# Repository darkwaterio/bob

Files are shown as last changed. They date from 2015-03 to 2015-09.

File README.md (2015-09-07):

#Bob Mk1 - "Ides"

This repository contains the hardware and firmware files for Mk1 of the Bob Float (codenamed "Ides").

This version was built for demonstration at the Big Bang Fair 2015 and is the first deployment of Bob. There are quite a few niggles to be fixed and updates that are planned for Bob based on the findings from this version, so it's not recommended that you spend much time with it - however, there will be a lot of cross-over of parts with the next version so you wouldn't need to rebuild everything for Mk2

Mk2 can be found at https://github.com/darkwaterfoundation/bob/tree/mk2

##Repository Layout

- hardware - contains three directories
  - stl contains the 3D printed parts files
  - svg contains the laser cutting files - you may need to alter the outside widths of circles based on the kerf of your cutter
  - pcb contains the eagle files for the power board and the processing board. The processing board is designed for use with the Spark Core. Some tweaks may be needed for the Spark Photon but you *should* be able to use the same board.
- firmware - contains the firmware for the demonstration version of Bob, this accepts commands over the Spark / Bob cloud and performs functions based on that (flashing lights / diving for x seconds) - it doesn't contain depth based functionality (other than reporting) as the tank we used was only a meter deep :)

##Preliminary Bill of Materials

https://docs.google.com/spreadsheets/d/1KixPCNF-eNdthVP5A6QqYoAs1JIhs3zF5F2K2lznduw/edit?usp=sharing

##Build instructions

Will be up soon

##License

This work is licensed under the Creative Commons Attribution-NonCommercial-ShareAlike 4.0 International License. To view a copy of this license, visit http://creativecommons.org/licenses/by-nc-sa/4.0/ or send a letter to Creative Commons, 444 Castro Street, Suite 900, Mountain View, California, 94041, USA.

*Some portions of code may be subject to different licensing agreements.

THE SOFTWARE IS PROVIDED “AS IS”, WITHOUT WARRANTY OF ANY KIND, EXPRESS OR IMPLIED, INCLUDING BUT NOT LIMITED TO THE WARRANTIES OF MERCHANTABILITY, FITNESS FOR A PARTICULAR PURPOSE AND NONINFRINGEMENT. IN NO EVENT SHALL THE AUTHORS OR COPYRIGHT HOLDERS BE LIABLE FOR ANY CLAIM, DAMAGES OR OTHER LIABILITY, WHETHER IN AN ACTION OF CONTRACT, TORT OR OTHERWISE, ARISING FROM, OUT OF OR IN CONNECTION WITH THE SOFTWARE OR THE USE OR OTHER DEALINGS IN THE SOFTWARE.

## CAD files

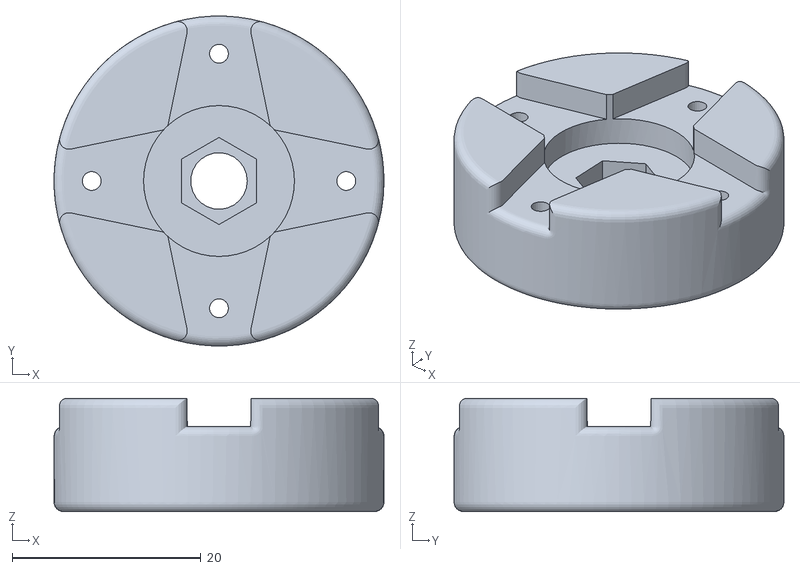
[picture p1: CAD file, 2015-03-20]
hardware/stl/servohorn.stl
35.0 x 35.0 x 12.0

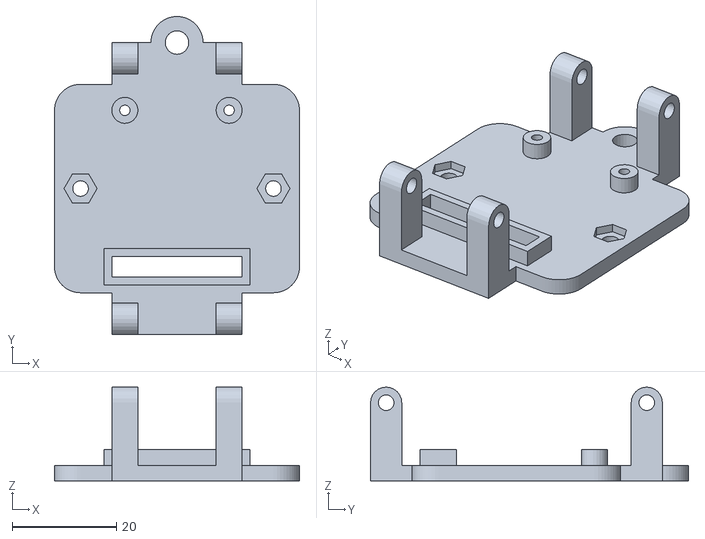
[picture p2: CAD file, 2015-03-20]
hardware/stl/gpsholder.stl
47.0 x 61.0 x 18.0

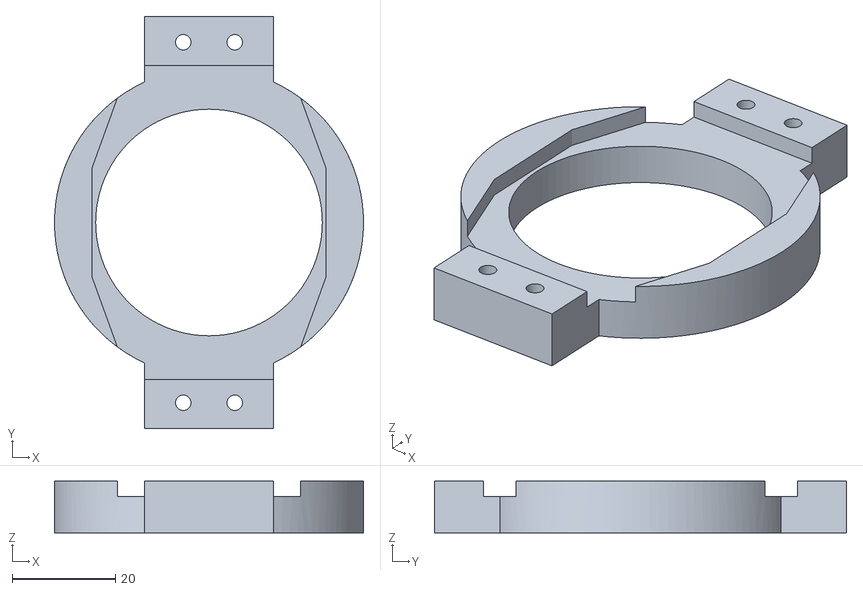
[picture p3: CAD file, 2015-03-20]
hardware/stl/syringeholder.stl
60.0 x 80.0 x 10.0

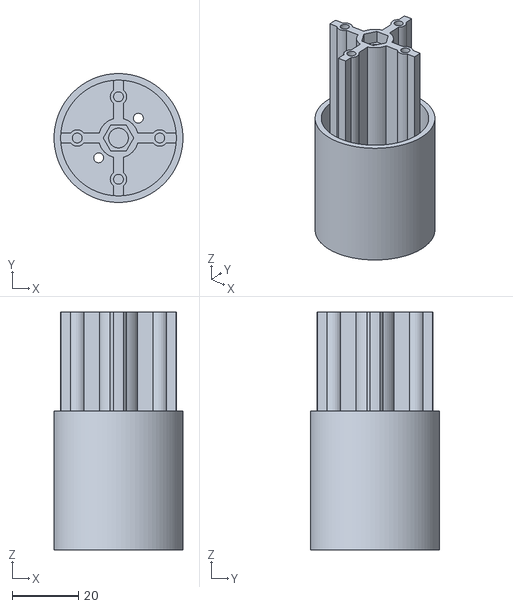
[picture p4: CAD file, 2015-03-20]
hardware/stl/plungerbody.stl
39.0 x 39.0 x 72.0

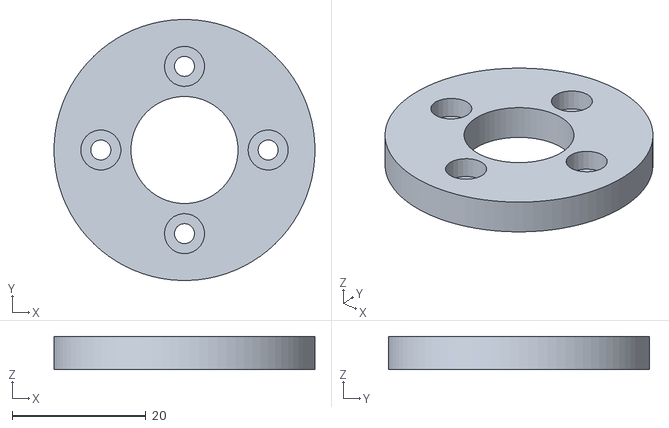
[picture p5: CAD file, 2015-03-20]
hardware/stl/bearingholder.stl
39.0 x 39.0 x 5.00

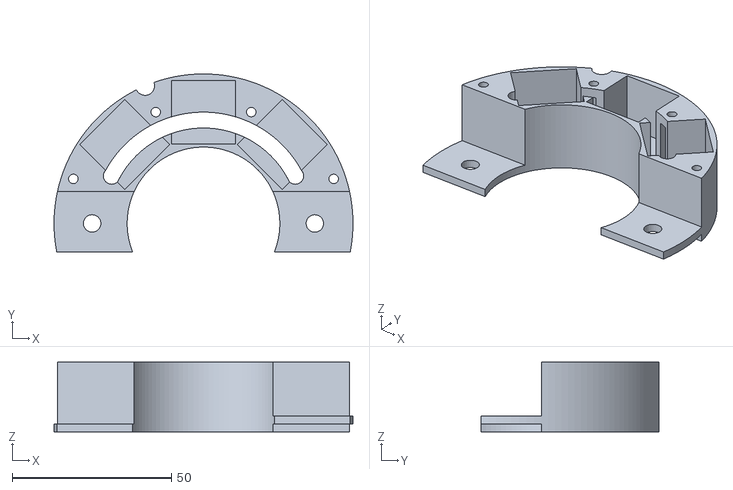
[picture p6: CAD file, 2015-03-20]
hardware/stl/batterydeepend.stl
94.0 x 56.0 x 22.0

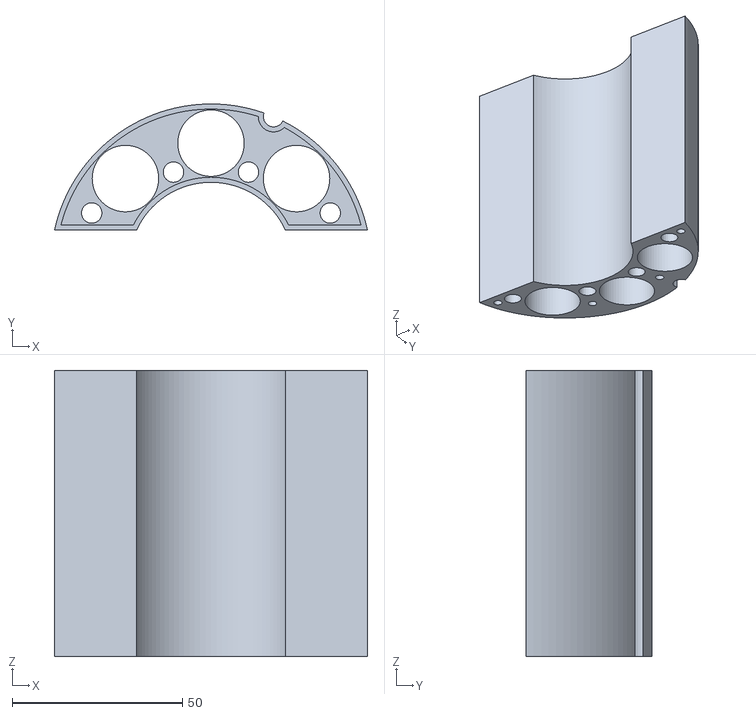
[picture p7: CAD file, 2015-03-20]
hardware/stl/outerbatteryholder.stl
91.8 x 37.0 x 84.0

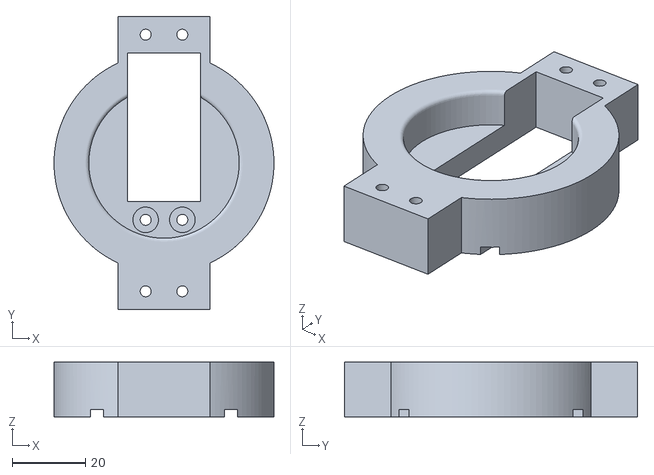
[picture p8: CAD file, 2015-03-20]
hardware/stl/servoholder.stl
60.0 x 80.0 x 15.0

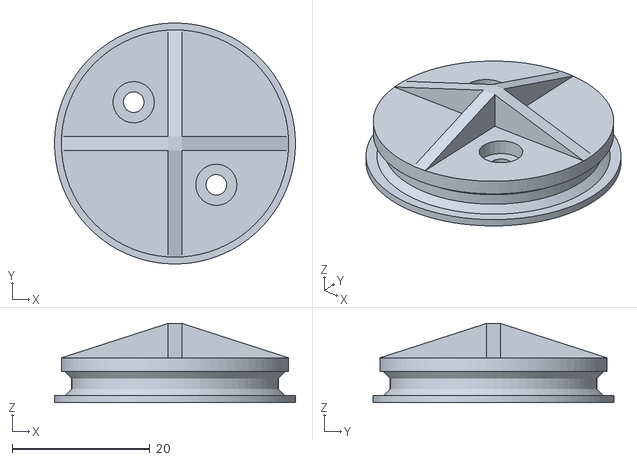
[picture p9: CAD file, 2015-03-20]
hardware/stl/plungerend.stl
35.0 x 35.0 x 11.5

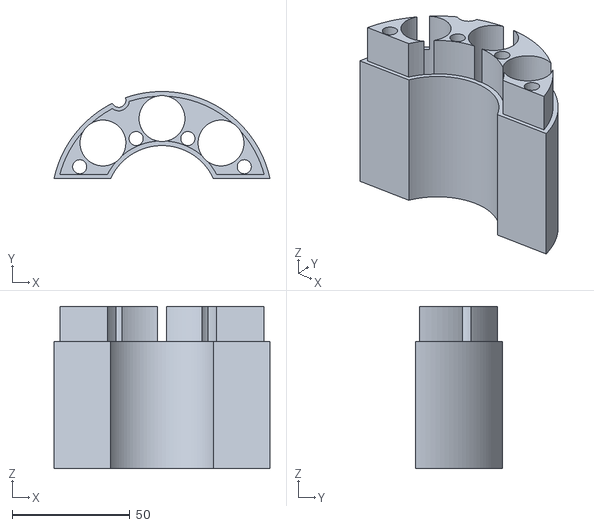
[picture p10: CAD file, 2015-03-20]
hardware/stl/innerbatteryholder.stl
91.8 x 37.0 x 69.0

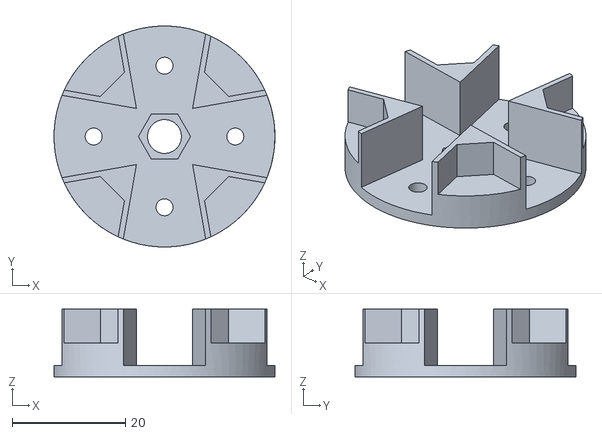
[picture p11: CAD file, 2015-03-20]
hardware/stl/magnetholder.stl
39.0 x 39.0 x 12.0

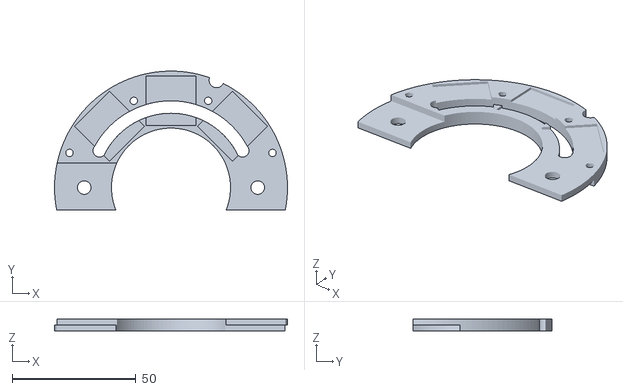
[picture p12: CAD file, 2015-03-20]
hardware/stl/batteryshallowend.stl
94.0 x 56.0 x 5.00

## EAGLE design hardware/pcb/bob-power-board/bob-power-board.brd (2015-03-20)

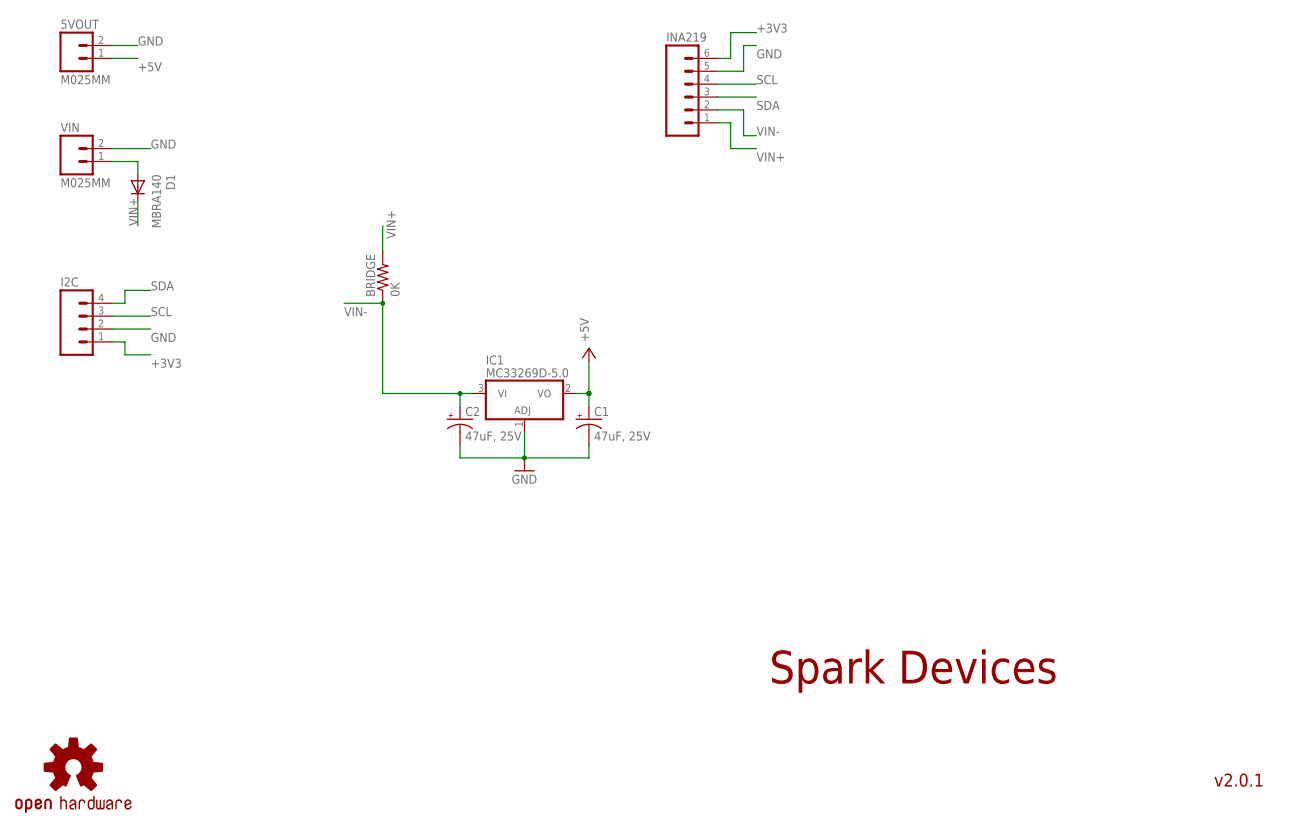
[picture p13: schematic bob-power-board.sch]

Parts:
5VOUT: M025MM; SCREWTERMINAL-5MM-2
BRIDGE: 0K; 1206
C1, C2: 47uF, 25V; CPOL-RADIAL-100UF-25V
D1: MBRA140; SMA-DIODE
I2C: M04LOCK; 1X04_LOCK
IC1: MC33269D-5.0; DPACK
INA219: M06LOCK; 1X06_LOCK
LOGO1: OSHW-LOGOM; OSHW-LOGO-M
VIN: M025MM; SCREWTERMINAL-5MM-2

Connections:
+3V3: I2C.1, INA219.6
+5V: 5VOUT.1, C1.1 (+), IC1.2 (VO)
GND: 5VOUT.2, C1.2 (-), C2.2 (-), I2C.2, IC1.1 (ADJ), INA219.5, VIN.2
unnamed: D1.A, VIN.1
SCL: I2C.3, INA219.4
SDA: I2C.4, INA219.3
VIN+: BRIDGE.2, D1.C, INA219.1
VIN-: BRIDGE.1, C2.1 (+), IC1.3 (VI), INA219.2

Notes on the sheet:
Spark Devices
v2.0.1

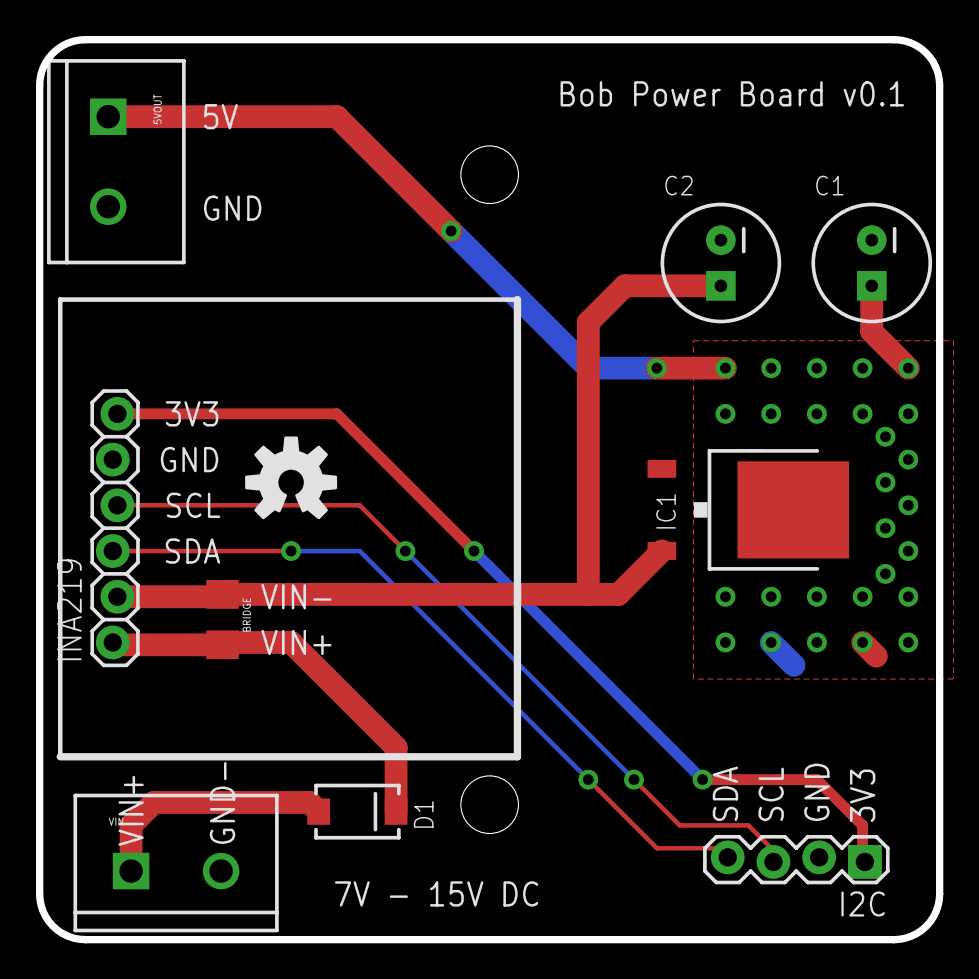
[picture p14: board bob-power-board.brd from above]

Board: 2 copper layers, 50.0 x 50.0 mm, 10 parts (0 on the bottom side), 8 nets.

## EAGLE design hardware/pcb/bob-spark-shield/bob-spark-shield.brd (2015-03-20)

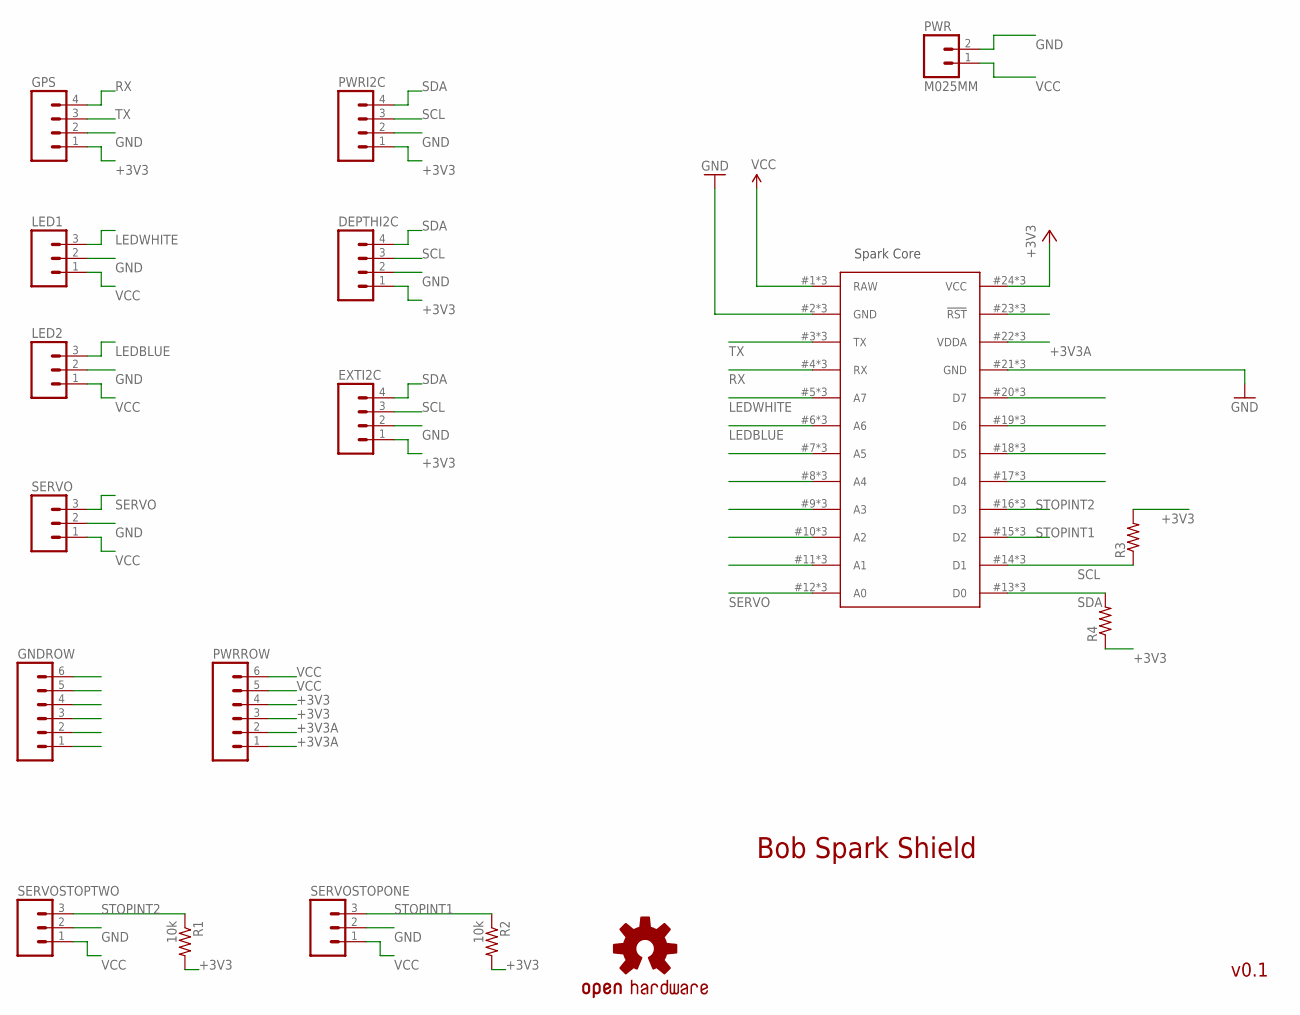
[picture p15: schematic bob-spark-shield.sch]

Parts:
DEPTHI2C: M04LOCK; 1X04_LOCK
EXTI2C: M04LOCK; 1X04_LOCK
GNDROW: M06LOCK; 1X06_LOCK
GPS: M04LOCK; 1X04_LOCK
LED1, LED2: M03LOCK; 1X03_LOCK
LOGO1: OSHW-LOGOM; OSHW-LOGO-M
PWR: M025MM; SCREWTERMINAL-5MM-2
PWRI2C: M04LOCK; 1X04_LOCK
PWRROW: M06LOCK; 1X06_LOCK
R1, R2: 10k; 0805
R3, R4: RESISTOR0805-RES; 0805
SERVO: M03LOCK; 1X03_LOCK
SERVOSTOPONE: M03LOCK; 1X03_LOCK
SERVOSTOPTWO: M03LOCK; 1X03_LOCK
U$1: SPARK_CORE; SPARK_CORE_STACKABLE

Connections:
+3V3: DEPTHI2C.1, EXTI2C.1, GPS.1, PWRI2C.1, PWRROW.3, PWRROW.4, R1.2, R2.2, R3.2, R4.1, U$1.24 (VCC), U$1.#24 (VCC), U$1.@24 (VCC)
+3V3A: PWRROW.1, PWRROW.2, U$1.22 (VDDA), U$1.#22 (VDDA), U$1.@22 (VDDA)
GND: DEPTHI2C.2, EXTI2C.2, GNDROW.1, GNDROW.2, GNDROW.3, GNDROW.4, GNDROW.5, GNDROW.6, GPS.2, LED1.2, LED2.2, PWR.2, PWRI2C.2, SERVO.2, SERVOSTOPONE.2, SERVOSTOPTWO.2, U$1.2 (GND), U$1.21 (GND), U$1.#2 (GND), U$1.#21 (GND), U$1.@2 (GND), U$1.@21 (GND)
LEDBLUE: LED2.3, U$1.6 (A6), U$1.#6 (A6), U$1.@6 (A6)
LEDWHITE: LED1.3, U$1.5 (A7), U$1.#5 (A7), U$1.@5 (A7)
unnamed: U$1.11 (A1), U$1.#11 (A1), U$1.@11 (A1)
unnamed: U$1.10 (A2), U$1.#10 (A2), U$1.@10 (A2)
unnamed: U$1.9 (A3), U$1.#9 (A3), U$1.@9 (A3)
unnamed: U$1.8 (A4), U$1.#8 (A4), U$1.@8 (A4)
unnamed: U$1.7 (A5), U$1.#7 (A5), U$1.@7 (A5)
unnamed: U$1.18 (D5), U$1.#18 (D5), U$1.@18 (D5)
unnamed: U$1.17 (D4), U$1.#17 (D4), U$1.@17 (D4)
unnamed: U$1.19 (D6), U$1.#19 (D6), U$1.@19 (D6)
unnamed: U$1.20 (D7), U$1.#20 (D7), U$1.@20 (D7)
unnamed: U$1.23 (!RST), U$1.#23 (!RST), U$1.@23 (!RST)
RX: GPS.4, U$1.4 (RX), U$1.#4 (RX), U$1.@4 (RX)
SCL: DEPTHI2C.3, EXTI2C.3, PWRI2C.3, R3.1, U$1.14 (D1), U$1.#14 (D1), U$1.@14 (D1)
SDA: DEPTHI2C.4, EXTI2C.4, PWRI2C.4, R4.2, U$1.13 (D0), U$1.#13 (D0), U$1.@13 (D0)
SERVO: SERVO.3, U$1.12 (A0), U$1.#12 (A0), U$1.@12 (A0)
STOPINT1: R2.1, SERVOSTOPONE.3, U$1.15 (D2), U$1.#15 (D2), U$1.@15 (D2)
STOPINT2: R1.1, SERVOSTOPTWO.3, U$1.16 (D3), U$1.#16 (D3), U$1.@16 (D3)
TX: GPS.3, U$1.3 (TX), U$1.#3 (TX), U$1.@3 (TX)
VCC: LED1.1, LED2.1, PWR.1, PWRROW.5, PWRROW.6, SERVO.1, SERVOSTOPONE.1, SERVOSTOPTWO.1, U$1.1 (RAW), U$1.#1 (RAW), U$1.@1 (RAW)

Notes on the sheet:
Spark Core
Bob Spark Shield
v0.1

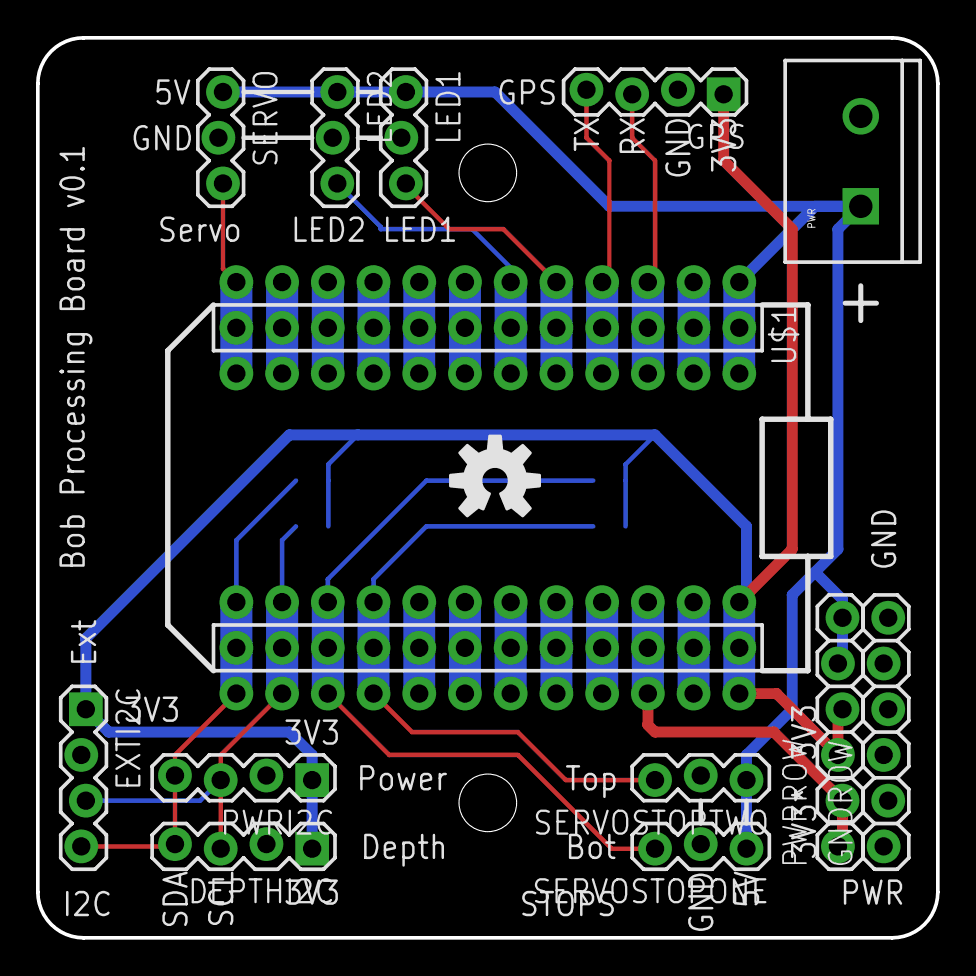
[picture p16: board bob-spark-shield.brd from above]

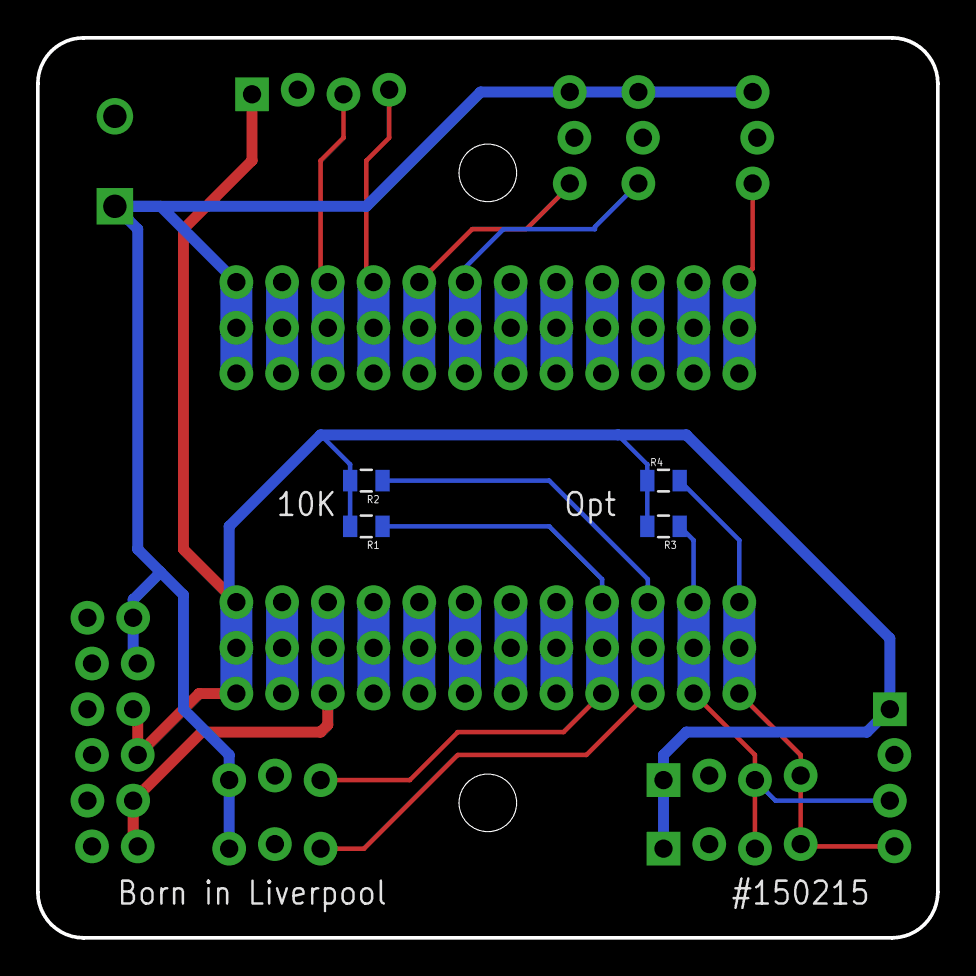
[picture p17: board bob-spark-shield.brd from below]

Board: 2 copper layers, 50.0 x 50.0 mm, 18 parts (4 on the bottom side), 23 nets.

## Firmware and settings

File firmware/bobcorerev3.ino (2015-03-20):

#include "application.h"

#include "Adafruit_GPS.h"
#include "ina219spark.h"
#include <math.h>
#include "MS5803_14.h"
//#include "SD.h"

// Lights based defines
#define PWM_FREQ 1000 // in Hertz (SET YOUR FREQUENCY)
#define WHITELIGHTS 0
#define BLUELIGHTS 1
uint16_t TIM_ARR = (uint16_t)(24000000 / PWM_FREQ) - 1; // Don't change! Calc's period.

//Popwer monitor declaration
Adafruit_INA219 ina219;

// GPS based defines
#define gpsSerial Serial1
Adafruit_GPS GPS( &gpsSerial );
bool readingGPS = true;
bool haveGPSLocation = false;
char GPSString[64];

float lastLat;
float lastLong;

// Depth and temperature defines
MS_5803 sensor = MS_5803(512);

// Servo / buoyancy based defines
Servo   mainServo;
#define DIVESPEED 120
#define SURFACESPEED 60
#define FULLSTOP 90

#define STOPPED 0
#define DIVING 1
#define SURFACING 2

#define MOTORSTOPPERIOD 70
#define MOTORDOWNOFFSET 1000

bool ascendOk = false;
bool descendOk = true;
bool ascending = false;
bool descending = false;
bool underWater = false;

int diveStatus = 0;

// SD Card based defines
// SOFTWARE SPI pin configuration - modify as required
// The default pins are the same as HARDWARE SPI
const uint8_t chipSelect = A2;    // Also used for HARDWARE SPI setup
const uint8_t mosiPin = A5;
const uint8_t misoPin = A4;
const uint8_t clockPin = A3;

// change this to match your SD shield or module;
//const int chipSelect = A2;
char dataString[100];
char sdata[10];
int lpcount=10;
bool recordingtoSD = false;

// Command based defines
#define CMDSTOP 0 // incase of emergency
#define CMDDIVE 1
#define CMDSURFACE 2 // prob not needed :)

#define CMDTEMPERATURE 3
#define CMDDEPTH 4
#define CMDLOCATION 5
#define CMDLIGHTS 6

#define CMDVOLTAGE 7
#define CMDAMPS 8

// Variables for the system
float temperature = 0;
float pressure = 0;
float depth = 0;
float prediveDepth = 0;
float targetDepth = 0;

unsigned long enddiveTime = 0;
bool autoMode = false;
unsigned long startdiveTime = 0;
unsigned long motorStop = 0;

float atmosPressure = 0; // set on first read of sensor
float depthOffset = 0;
float freshWaterDensity = 1.019716;
float saltWaterDensity = 0.9945;

bool inFreshWater = true;

float voltage = 0;
float current = 0;
float startingVoltage = 0;
float warningVoltage = 5.99;

char powerString[64];

// Hold the external arguments - spark core limited to 63 chars
char externalCommand[64];

// Cloud connection variables
bool connectedtoCloud = true;

/* Definitions */
void beginDive( int timePeriod );

// What mode are we using - non-demo will switch to manual
//SYSTEM_MODE(AUTOMATIC);
SYSTEM_MODE(MANUAL);

// The main code
void setup() {

    Serial.begin(9600);
    Serial.println("started!");

    delay(5000);

    // Force the I2C to stretch the clock
    Wire.setSpeed(CLOCK_SPEED_100KHZ);
    Wire.stretchClock(true);
    Wire.begin();

    // Set up the power monitor
    initialisePower();

    // Set the pins to output and test flash
    initialiseLights();

    // Set up the Depth sensor
    initialiseDepth();

    // Set up the GPS
    initialiseGPS();

    // Set up the servo for output
    initialiseServo();

    // Set up the SD card
    //initialiseSD();

    // Spark functions

    // First we'll connect now that everything else is done
    if( !Spark.connected() ) {
      Spark.connect();
    }

    // processexternal - due to limited number of functions, this handles most operations
    Spark.function("process", processCommand );

    // GPS string
    Spark.variable("GPS", &GPSString, STRING );
    // Power string
    Spark.variable("voltage", &powerString, STRING );
}

void loop() {

    readDepth();

    readPower();

   if( readingGPS ) {
       char c = GPS.read();
       //Serial.println( c);
       // if you want to debug, this is a good time to do it
       if( parseGPS() ) {
           // Do nothing for now - that's all we need for this version
       }
   }

  if( motorStop != 0 && motorStop < millis() ) {
    motorStop = 0;
    //fullStop();
    if( diveStatus == DIVING ) {
      stopDive();
    } else {
      stopSurface();
    }
  }

    // checks if we are underwater
   if( areWeUnderwater() || diveStatus == DIVING ) {
     // Battery power check
     if( !canWeDive() ) {
       // battery is running low - get us out of here
       beginSurface();
       // flash a bit
       errorFlash( 3 );
     }

     if( enddiveTime != 0 && enddiveTime < millis() ) {
       // We are underwater and have had a dive time set
       beginSurface();
     }

   }

   if( autoMode && startdiveTime !=0 && startdiveTime < millis() ) {
     beginDive( 240 );
   }


    // If we are connected to the cloud then we need to process commands on a regular basis
    if( Spark.connected() ) {
        Spark.process();
    }

}

/*
* Control code
*
* Commands some in the format
* codenumber:parameter1/parameter2/parameter3
*
* for multiple commands in a single send parameters can be split
*
* codenumber:parameter1/parameter2:parameter1/parameter2
*
*/

/*#define CMDSTOP 0 // incase of emergency
#define CMDDIVE 1
#define CMDSURFACE 2 // prob not needed :)

#define CMDTEMPERATURE 3
#define CMDDEPTH 4
#define CMDLOCATION 5
#define CMDLIGHTS 6

#define CMDVOLTAGE 7
#define CMDAMPS 8
*/

int processCommand( String args ) {

    //Serial.println( args );

    // Get things out of a string for processing
    args.toCharArray( externalCommand, 63 );

    char* receivedCommand = strtok(externalCommand, ":");
    //char* receivedArguments = strtook( NULL, ":" );

    int command = atoi( receivedCommand );

    switch(command) {
        case 0: { // Stop and reset
                Serial.println( "processing fullstop" );
                fullStop();

                ascendOk = true;
                descendOk = true;

                autoMode = false;
                break;
            }
        case 1: { // Dive
                Serial.println( "processing dive" );
                if( canWeDive() ) {
                    char* timePeriodCommand = strtok(NULL, ":");
                    int timePeriod = atoi( timePeriodCommand );
                    beginDive( timePeriod );
                } else {
                  // Warn some how
                  errorFlash( 3 );
                }
                break;
            }
        case 2: { // Surface
                Serial.println( "processing surface" );
                // In all likelyhood this will never get called in real life as no wifi underwater
                beginSurface();
                break;
            }
        case 3: { // Temperature
                Serial.println( "processing temperature" );
                return (int)(temperature * 100);
                //fullStop();
                break;
            }
        case 4: { // Depth
                Serial.println( "processing depth" );
                return (int)(depth * 100);
                break;
            }
        case 5: {
                Serial.println( "processing gps" );

                char* GPSCommand = strtok(NULL, ":");
                int gpsc = atoi( GPSCommand );

                if( gpsc == 0 ) {
                    // Put GPS to sleep
                    if( GPS.standby() ) {
                        return 1;
                    } else {
                        return 0;
                    }
                } else if ( gpsc == 1) {
                    // Wake GPS
                    if( GPS.wakeup() ) {
                        return 1;
                    } else {
                        return 0;
                    }
                } else {
                    // Just return the GPS information
                    if( returnGPS() ) {
                        return 1;
                    } else {
                        return 0;
                    }
                }
                break;
            }
        case 6: {
                Serial.println( "processing lights" );

                char* lightCommand = strtok(NULL, ":");
                int lightArray = atoi( lightCommand );

                char* lightNumberCommand = strtok(NULL, ":");
                int lightNumber = atoi( lightNumberCommand );

                if( lightNumber == 0 ) {
                    lightsOff( lightArray );
                } else {
                    lightsOn( lightArray, lightNumber );
                }
                break;
            }
        case 7: { // voltage
                Serial.println( "processing voltage" );
                return (int)(voltage * 100);
                break;
            }
        case 8: { // current
                Serial.println( "processing current" );
                return (int)(current * 100);
                break;
            }
        case 9: { // Auto dive mode
                autoMode = true;
                if( canWeDive() ) {
                    beginDive( 240 );
                } else {
                  // Warn some how
                  errorFlash( 3 );
                }
                return 1;
                break;
            }
    }

    return 1;

}

/*
* Depth sensor code
*/
void initialiseDepth() {

    if (sensor.initializeMS_5803()) {
        Serial.println( "MS5803 CRC check OK." );
    }
    else {
        Serial.println( "MS5803 CRC check FAILED!" );
    }

}

void readDepth() {

  // Read the sensor
  sensor.readSensor();

  // Store the values
  temperature = sensor.temperature();
  pressure = sensor.pressure();

  // We may be on the default - but set it to our pressure anyway
  if( atmosPressure == 0 ) {
    atmosPressure = pressure;
  }

  // calculate depth - based on openrov calculations
  if( inFreshWater ) {
    depth = (pressure - atmosPressure) * freshWaterDensity / 100;
  } else {
    depth = (pressure - atmosPressure) * saltWaterDensity / 100;
  }

  depth = depth - depthOffset;

}

/*
* Power monitor code
*/
void initialisePower() {

  // Set up the voltage monitor
  ina219.begin();

}

void readPower() {

  float shuntvoltage = ina219.getShuntVoltage_mV();

  voltage = ina219.getBusVoltage_V();
  current = ina219.getCurrent_mA();

  voltage = voltage + (shuntvoltage / 1000);

  if( startingVoltage == 0 ) {
    startingVoltage = voltage;
  }

  //powerString
  sprintf( powerString, "{\"voltage\":%f,\"amps\":%f}", voltage, current);
}

/*
* SD Card code
*/
void initialiseSD() {

    /*
    // see if the card is present and can be initialized:
  if (!SD.begin(chipSelect)) {
      Serial.println("Card failed, or not present");
      recordingtoSD = false;
  }
  */

}

/*
* Motors code
*/
void initialiseServo() {

    mainServo.attach(A0);  // attaches the servo on the A0 pin to the servo object
    mainServo.write( FULLSTOP );

    pinMode( D2, INPUT );
    pinMode( D3, INPUT );

    /*attachInterrupt( D3, stopDive, FALLING);*/
    attachInterrupt( D3, stopSurface, FALLING);
    attachInterrupt( D2, stopSurface, FALLING);

    ascendOk = true;
    descendOk = true;

}

void beginDive( int timePeriod = 30 ) {

    if( descendOk ) {
        // stop the servo first
        fullStop();

        allLightsOn( 1 );

        // We'll store this for later on
        prediveDepth = returnDepth();
        // Need to store the time we should start surfacing again
        enddiveTime = millis() + (timePeriod * 1000);

        motorStop = millis() + (MOTORSTOPPERIOD * 1000);

        startdiveTime = 0;

        mainServo.write( DIVESPEED );

        ascendOk = true;

        diveStatus = DIVING;

        // turn the wifi off - we don't need it underwater
        closeExternalInterfaces();

        //descending = true;
        //ascending = false;
    }

}

void beginDiveNoTimeout() {

    if( descendOk ) {
        // stop the servo first
        fullStop();

        // We'll store this for later on
        prediveDepth = returnDepth();
        // Need to store the time we should start surfacing again
        enddiveTime = 0;

        mainServo.write( DIVESPEED );

        ascendOk = true;

        diveStatus = DIVING;

        // turn the wifi off - we don't need it underwater
        closeExternalInterfaces();

        //descending = true;
        //ascending = false;
    }

}

void beginSurface() {

    if( ascendOk ) {
        // stop the servo first
        fullStop();

        // Flash the lights to show that the surface is starting
        allLightsOn( 2 );

        // Set end dive time to 0 as we are no longer diving
        enddiveTime = 0;
        motorStop = 0;
        /*motorStop = millis() + ( (MOTORSTOPPERIOD) * 1000) + MOTORDOWNOFFSET;*/
        // start the surfacing
        mainServo.write( SURFACESPEED );

        descendOk = true;

        diveStatus = SURFACING;

        Serial.println( "Surfacing");

        //ascending = true;
        //descending = false;
    }

}

void stopDive() {

    // stop the servo first
    fullStop();

    // We can't descend anymore
    descendOk = false;
    // But we can ascend
    ascendOk = true;
    // Change the status
    //descending = false;

    Serial.println( "stopping dive" );


}

void closeExternalInterfaces() {

    Serial.println( "wifi off" );

    // Turn off the wifi
    WiFi.off();
    // Turn off the GPS
    GPS.standby();

}

void openExternalInterfaces() {

  Serial.println( "wifi on");

  // Switch the wifi back on and connect to the cloud
  Spark.connect();
  // Turn the GPS back on
  GPS.wakeup();

}

bool areWeUnderwater() {
  if( returnDepth() < prediveDepth ) {
    // we are under water
    return true;
  }
}

bool canWeDive() {
  if( returnVoltage() <= warningVoltage ) {
    return false;
  } else {
    return true;
  }

}

void stopSurface() {

    // stop the servo first
    fullStop();

    // We can't descend anymore
    ascendOk = false;
    // But we can ascend
    descendOk = true;
    // Change the status
    //ascending = false;
    motorStop = 0;

    Serial.println( "stop surface" );

    diveStatus = STOPPED;

    // Flash the lights to show that the surface is stopped
    allLightsOn( 1 );

    // We need to put the wifi back on at this point, so we'll do a spark connect to handle both
    openExternalInterfaces();

    if( autoMode ) {
      startdiveTime = millis() + (60  * 1000);
    }

}

void fullStop() {
    mainServo.write( FULLSTOP );
}

/*
*   Lights code
*/
void initialiseLights() {

    pinMode(A6, OUTPUT); // sets the pin as output
    pinMode(A7, OUTPUT); // sets the pin as output

    allLightsOn( 2 );
}

void lightsOn( int lightArray, int lightTimes ) {

    if( lightTimes == 99 ) {
        // We are using this as a one time switch on of lights
        if( lightArray == WHITELIGHTS ) {
            analogWrite2(A6, 255);
        } else {
            analogWrite2(A7, 255);
        }
    } else {

        if( lightTimes <= 9 ) {
            // restrict for sensible reasons
            // switch off first
            lightsOff( lightArray );
            for( int lightCount = 1; lightCount <= lightTimes; lightCount++ ) {
                if( lightArray == WHITELIGHTS ) {
                    analogWrite2(A6, 255);
                } else {
                    analogWrite2(A7, 255);
                }
                delay( 500 );
                lightsOff( lightArray );
                delay( 500 );
            }
        }

    }



}

void allLightsOn( int lightTimes ) {

    if( lightTimes == 99 ) {
        // We are using this as a one time switch on of lights
        analogWrite2(A6, 255);
        analogWrite2(A7, 255);
    } else {

        if( lightTimes <= 9 ) {
            // restrict for sensible reasons
            // switch off first
            allLightsOff();
            for( int lightCount = 1; lightCount <= lightTimes; lightCount++ ) {
                analogWrite2(A6, 255);
                analogWrite2(A7, 255);
                delay( 500 );
                allLightsOff();
                delay( 500 );
            }
        }

    }
}

void lightsOff( int lightArray ) {

    if( lightArray == WHITELIGHTS ) {
        analogWrite2(A6, 0);
    } else {
        analogWrite2(A7, 0);
    }
}

void allLightsOff() {
    analogWrite2(A6, 0);
    analogWrite2(A7, 0);
}

void errorFlash( int errorCode ) {
  allLightsOn( errorCode );
}

// Functions that read from the various sensors attached to the system

float returnDepth() {

  if( depth == 0 ) {
    // we need to grab it as for some reason it hasn't been set
    readDepth();
  }

  return depth;

}

float returnTemperature() {

  if( temperature == 0 ) {
    // we need to grab it as for some reason it hasn't been set - same function that sets the Depth
    readDepth();
  }

  return temperature;

}

float returnVoltage() {

  if( voltage == 0 ) {
    // we need to set it as for some reason it hasn't been set
    readPower();
  }

  return voltage;

}

float returnCurrent() {

  if( current == 0 ) {
    // we need to set it as for some reason it hasn't been set - same function as Voltage
    readPower();
  }

  return current;

}

bool returnGPS() {

    if( haveGPSLocation ) {

        sprintf( GPSString, "{\"lat\":%f,\"lng\":%f}", GPS.latitudeDegrees, GPS.longitudeDegrees);

      //GPSString
        Serial.print( "Lat:" );
        Serial.print( GPS.latitudeDegrees, 4 );
        Serial.println( GPS.lat );

        Serial.print( "Long:" );
        Serial.print( GPS.longitudeDegrees, 4 );
        Serial.println( GPS.lon );

        return true;
    } else {
        Serial.println( "No location");
        sprintf( GPSString, "{\"lat\":%f,\"lng\":%f}", 0, 0);

        return false;
    }

}

/*
* GPS code
*/
void initialiseGPS() {

    // 9600 NMEA is the default baud rate for Adafruit MTK GPS's- some use 4800
    GPS.begin(9600);
    gpsSerial.begin(9600);

    // uncomment this line to turn on RMC (recommended minimum) and GGA (fix data) including altitude
    GPS.sendCommand(PMTK_SET_NMEA_OUTPUT_RMCGGA);

    // Set the update rate
    GPS.sendCommand(PMTK_SET_NMEA_UPDATE_1HZ);   // 1 Hz update rate
    // For the parsing code to work nicely and have time to sort thru the data, and
    // print it out we don't suggest using anything higher than 1 Hz

    // Request updates on antenna status, comment out to keep quiet
    GPS.sendCommand(PGCMD_NOANTENNA);

}

bool parseGPS() {

    // if a sentence is received, we can check the checksum, parse it...
  if (GPS.newNMEAreceived()) {
    // a tricky thing here is if we print the NMEA sentence, or data
    // we end up not listening and catching other sentences!
    // so be very wary if using OUTPUT_ALLDATA and trytng to print out data
    //Serial.println(GPS.lastNMEA());   // this also sets the newNMEAreceived() flag to false

    if (!GPS.parse(GPS.lastNMEA()))   {
        // this also sets the newNMEAreceived() flag to false
        return false;  // we can fail to parse a sentence in which case we should just wait for another
    } else {
        lastLat = GPS.latitude;
        lastLong = GPS.longitude;
        haveGPSLocation = true;
        return true;
    }

  }

  return false;

}
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

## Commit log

2014-12-16 Added initial STP files
    [dome.step, electronicsshelf.step, openfoot.step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]
2014-12-16 Added initial 3D printing STL
    [servosupport.stl, syringe.step, syringeholder.stl]
2015-03-20 change directory format to new layout
    [dome.step, electronicsshelf.step, openfoot.step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]
2015-03-20 Added PCB files
    Added the eagle files for the processor board and power board
    [bob-power-board.brd, bob-power-board.sch, bob-spark-shield.brd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]
2015-03-20 Initial STL files
    [batterydeepend.stl, batteryshallowend.stl, bearingholder.stl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]
2015-03-20 re-orient some parts for better printing
    [bearingholder.stl, gpsholder.stl, plungerbody.stl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]
2015-03-20 Quick update
    [servohorn.stl]
2015-03-20 Added 5mm and 3mm cutting files
    Needs multiples of some pieces, just put one of each on the files.

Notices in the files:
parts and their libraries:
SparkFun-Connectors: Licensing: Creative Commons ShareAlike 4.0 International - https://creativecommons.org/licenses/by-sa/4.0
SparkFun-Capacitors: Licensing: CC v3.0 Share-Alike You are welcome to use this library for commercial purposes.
